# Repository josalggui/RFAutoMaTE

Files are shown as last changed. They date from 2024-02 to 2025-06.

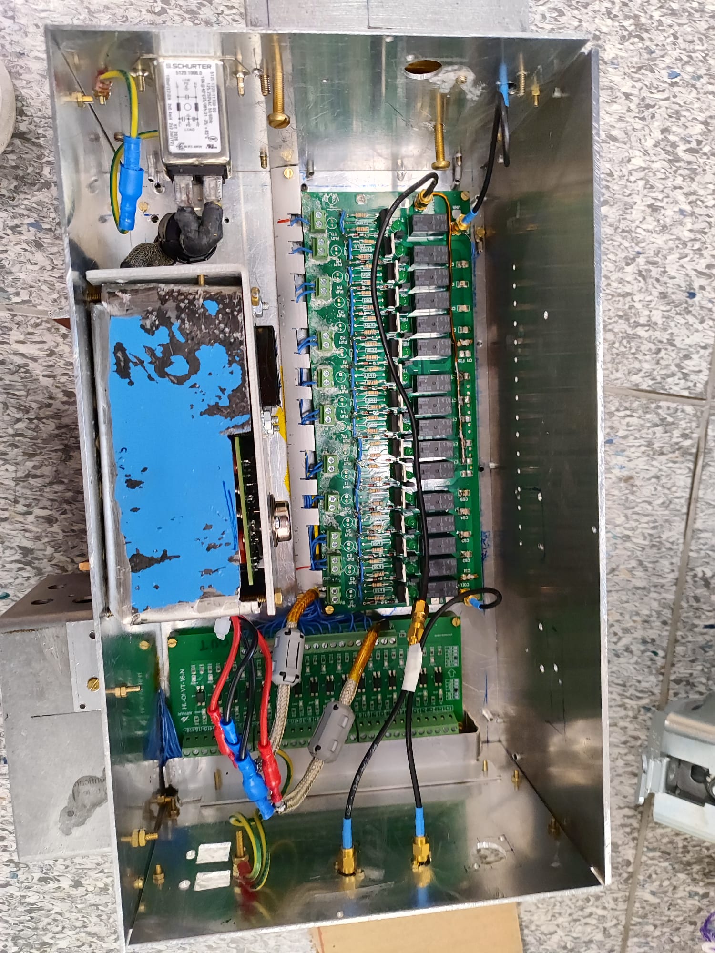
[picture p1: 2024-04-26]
figures/caja 1.jpg

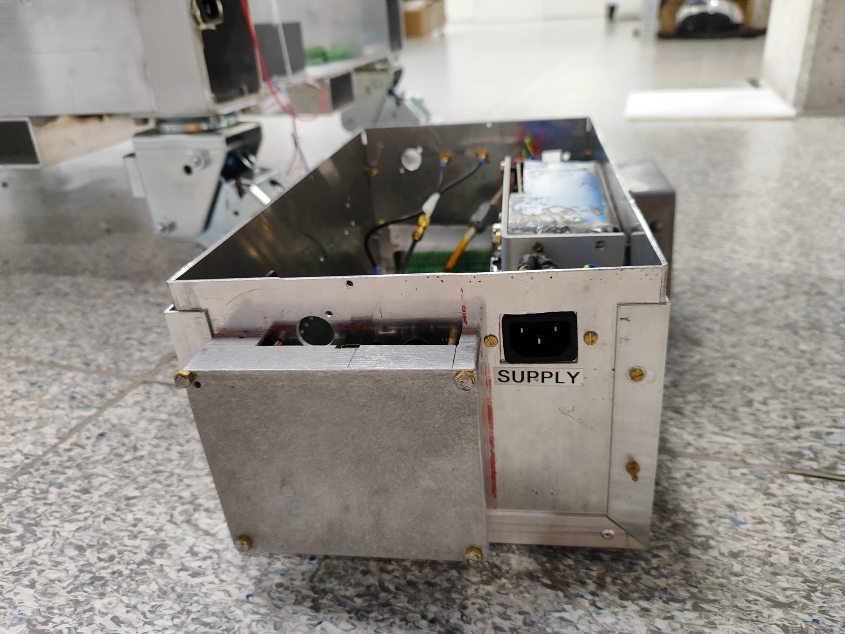
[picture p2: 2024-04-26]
figures/caja 3.jpg

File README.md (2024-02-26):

# RFAutoMaTE - Radio Frequency Automatic Matching and Tuning Equipment

Welcome to RFAutoMaTE, **R**adio **F**requency **Auto**matic **Ma**tching and **T**uning **E**quipment, our go-to solution for seamless Radio Frequency (RF) coil matching and tuning in low-field (< 100 mT) MRI scanners.

## Overview

RFAutoMaTE is designed to provide efficient and automatic matching of RF coils to ensure optimal performance and signal quality in Magnetic Resonance Imaging (MRI) systems.

## Features

- **RF Precision:** Achieve precise Radio Frequency coil matching.
- **AutoMaTE Automation:** Streamlined process with AutoMaTE (Automatic Matching and Tuning) automation.
- **Tuning Efficiency:** Efficient T (Tuning) for enhanced imaging performance.
- **Ease of Use:** E (Equipment) designed for user-friendly operation.

## Getting Started (TODO)

To get started with RFAutoMaTE, follow these simple steps:

1. **Installation:** Clone the repository to your local machine.
   ```bash
   git clone https://github.com/mriLab-i3M/RFAutoMaTE.git

2. **Configura.tion:** Adjust RFAutoMaTE settings according to your system requirements.
3. **Usage:** Integrate RFAuotMaTE into your MRI system for automatic RF coil matching and tuning.

## Testing
To test if relays are working properly, load the `test_arduino.ino` into the arduino and power the RFAutoMaTE. The relays should blink sequencitally.

If everything is ok. load the `autotunig_arduino.ino` into the arduino. Now the user can turn on/off relays by serial communication.

RFAutoMaTE is able to change the impedance by de/activating relays that chanes capacitance to a T circuit. The T circuit includes a series, tuning and matching capacitors.

<img src="figures/Circuit.png">

Each capacitance has up to 5 capacitors, giving a total of 15 pins. An additional
digital signal (TTL) allow the user to switch the tuning matching between the
Tx/Rx switch to run MRI experiments or to the VNA to measure the coil impedance.

User can control the status by sending a set of 16 (15 capacitors + 1 switch) digits to de/activate the
capacitance.
0->Capacitor activated
1->Capacitor deactivated

Last digit correspond the switching between VNA and TxRx switch:
0->TxRx switch
1->VNA

For example, if the user wants to activate all capcitors and connect to TxRx switch:
`0000000000000000`

For the moment, the code does not check the number of digits. So make sure that
the number of digits is 16, otherwise, arduino can get frozen.

## Contributors
1. [Rubén Bosch Esteve](https://github.com/RubenBoschEsteve), circuit design and pcb design
2. [José Miguel Algarín Guisado](https://github.com/josalggui), circuit design, arduino code, integration with [MaRGE](https://github.com/josalggui/MaRGE)

## License
RFAutoMaTE is released under the GNU General Public License (GPL) v3.0.

Feel free to reach out if you have any questions or need assistance.

Happy matching and tuning!

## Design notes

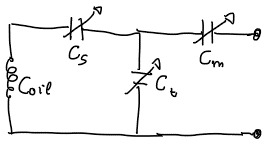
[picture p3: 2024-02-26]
figures/Circuit.png

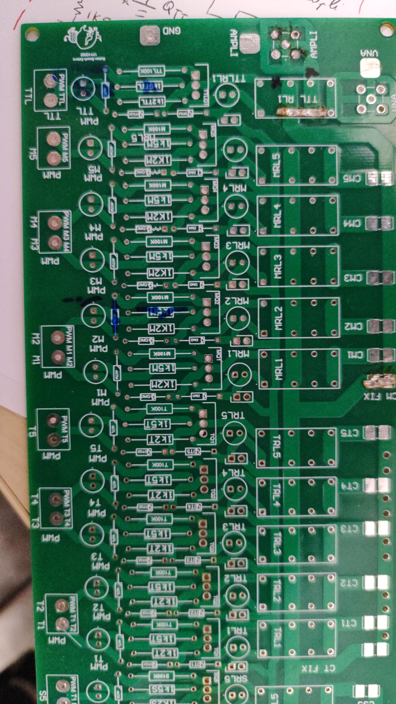
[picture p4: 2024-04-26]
figures/pcb sin montar.jpg

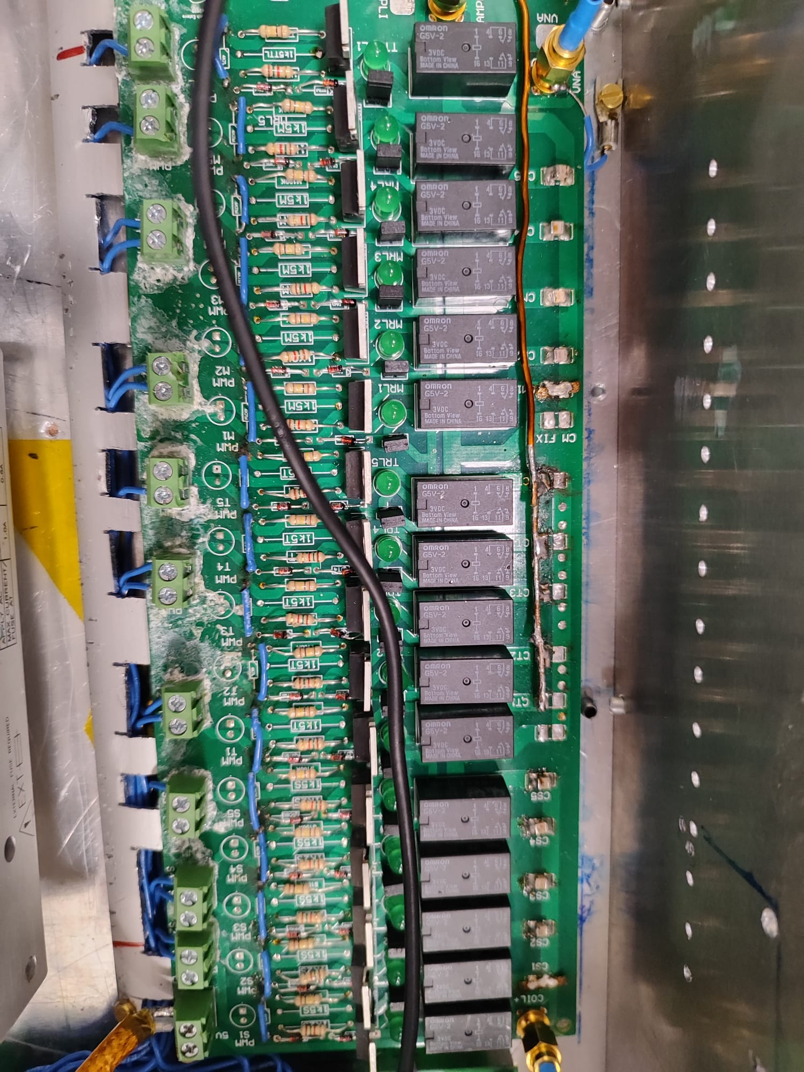
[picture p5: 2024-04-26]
figures/pcb montada 1.jpg

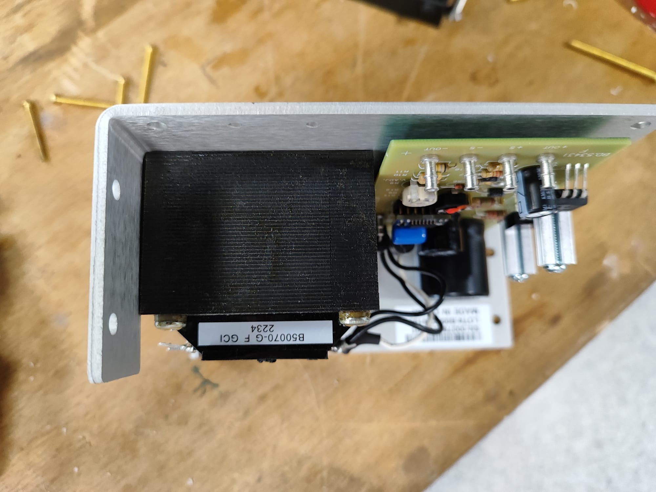
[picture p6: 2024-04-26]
figures/fuente lineal.jpg

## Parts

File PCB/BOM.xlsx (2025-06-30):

Descripción | References | Part number | Link | Quantity | Observaciones
Rele | SRL1…5, TRL1…5, MRL1…5, TTL RL1 | G5V-2-DC3 | MOUSER (https://www.mouser.es/ProductDetail/Omron-Electronics/G5V-2-DC3?qs=sGAEpiMZZMsyYdr3R27aV%252B0%2FGArKNh1e) | 16 | EC - 0039
Mosfet | SQ1…5, TQ1…5, MQ1…5, TTL Q1 | IRFZ44N Mosfet o IRFZ44NPBF | MOUSER (https://www.mouser.es/ProductDetail/Infineon-Technologies/IRFZ44NPBF?qs=9%252BKlkBgLFf24zghzPg2f9g%3D%3D) | 16 | EC - 0038
Jumper Macho | J1-J16 | 251-8086 Jumper macho | RS (https://es.rs-online.com/web/p/conectores-macho-para-pcb/2518086) | 16 | Se ponen en el mismo lugar que los Jumper hembra (EC - 0026)
Diodo | DT1..DT5,DM1…DM5,DS1..DS5,DTQ1..DTQ5,DMQ1…DMQ5,DSQ1..DSQ5,DTTL1,DTTLQ1 | DIODO 1N4148TA | DIGIKEY (https://www.digikey.es/es/products/detail/on-semiconductor/1N4148TA/1532747) | 32 | EC - 0048
Resistencia 1.2k | 1.2k | MRS16000C1201FCT00 | digikey (https://www.digikey.es/es/products/detail/vishay-beyschlag-draloric-bc-components/MRS16000C1201FCT00/5063751) | 16 | EC - 0034
Resistencia 100k | 100k | SFR2500001003JA500 | digikey (https://www.digikey.es/es/products/detail/vishay-beyschlag-draloric-bc-components/SFR2500001003JA500/5065363) | 16 | EC - 0033
Terminal regleta PCB | PMW S1..5, PMW T1..5, PMW M1..5, COIL, GND, 5V | 691213710002 | RS (https://es.rs-online.com/web/p/bornes-para-pcb/8267282?searchId=7f03fc5e-c5a5-46d9-938e-7147ac300166&gb=s) | 11 | EC - 0035
LED | DSRL1..5,DTRL1..5,DMRL1..5,DTTL5 | SLR-56MG3F | DIGIKEY (https://www.digikey.es/es/products/detail/rohm-semiconductor/SLR-56MG3F/636990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) | 16 | EC - 0031
Jumper hembra | J1-J16 | AKSCT/Z BLACK | rs (https://es.rs-online.com/web/p/jumpers-y-derivadores/6742397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) | 16 | EC - 0026
SMA PCB |  | 901-144-8RFX | rs (https://es.rs-online.com/web/p/conectores-coaxiales/1440894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) | 3 | RF - 0007

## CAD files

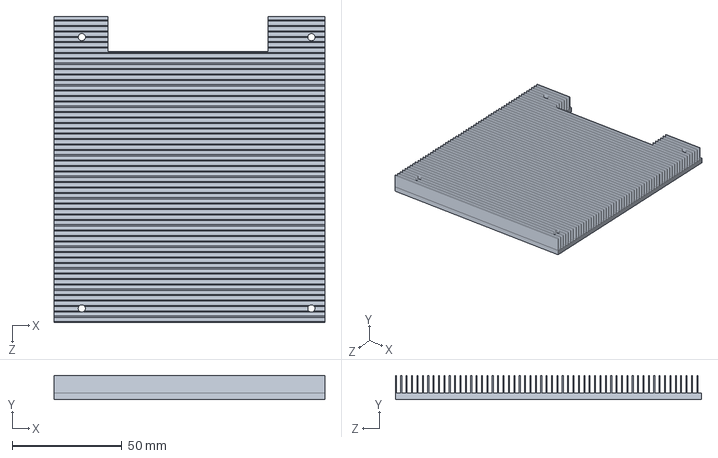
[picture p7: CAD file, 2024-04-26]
Disipador/disipador V2.SLDPRT
123.7 x 11.0 x 139.8 mm

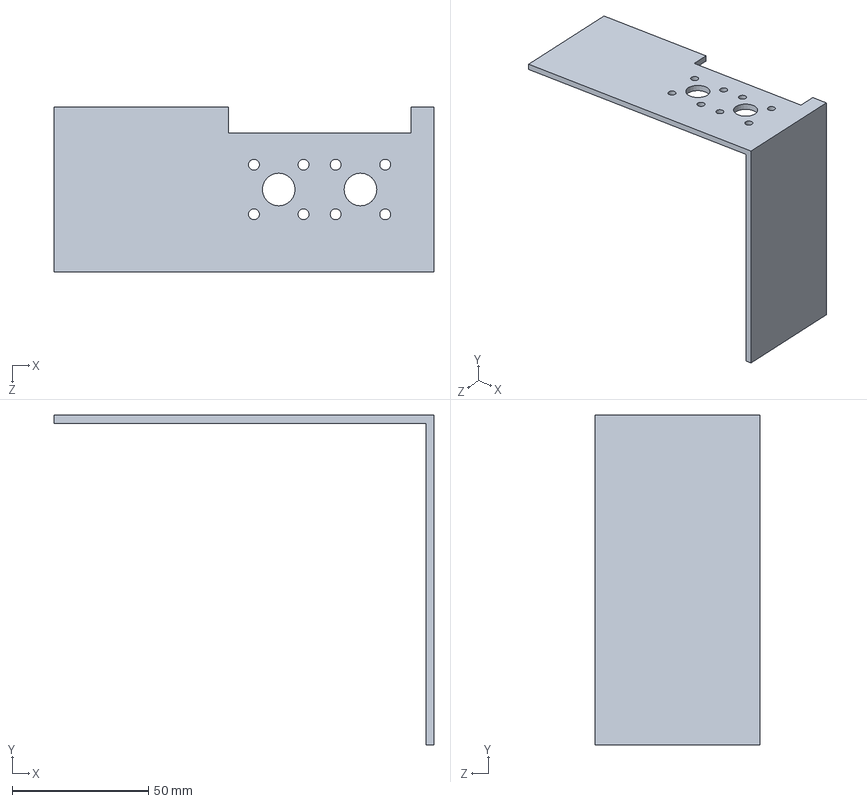
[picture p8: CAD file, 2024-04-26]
Disipador/fuente lineal V2.SLDPRT
139.5 x 121.0 x 60.5 mm

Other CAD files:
Disipador/disipador V2.STL
Disipador/fuente lineal V2.STL

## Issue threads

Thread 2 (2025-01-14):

Implementation of RFAutoMate

LeoMcBills, 2025-01-14:
Hello @josalggui, could you be having more literature on RFAutoMate otherwise I want to implement it for our lab in Uganda but I still do not understand the criteria for choosing the capacitor values.

Also, is there a way I could open the PCB files in KiCad?

Thanks!

josalggui, 2025-02-09:
Hi @LeoMcBills. I apologize for the long delay to answer, but I have important deadlines. Unfortunately I do not have time now to do documentation. I can send you by email what I have from our lab notes if you want. Also, if you want to contribute by doing some documentation based on our notes, it will be great!

LeoMcBills, 2025-02-09:
Hello @Josalggui/Rfautomate,
I hope this email finds you well. It is alright, sending me your notes by
email (this or on  ***@***.***)will be greatly appreciated and I
will update the documentation based on this as I am happy to do so.

Thanks very much for your support always.

Leo

On Sun, Feb 9, 2025, 7:03 PM José Miguel Algarín Guisado <
***@***.***> wrote:

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

--
*DISCLAIMER*

This email and its attachments are, unless the context
clearly indicates otherwise, the property of Mbarara University of Science
and Technology. It is confidential, private and intended for the addressee
only. If you are not an intended recipient you must not use, disclose,
distribute, copy, print or rely on this email. Mbarara University of
Science and Technology accepts no liability to anyone whatsoever for any of
the contents of the email or any of its attachments.

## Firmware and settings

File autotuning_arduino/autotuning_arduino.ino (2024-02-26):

/*
Code to control the RFAutoMaTE with arduino.
Ph.D. José Miguel Algarín Guisado
mriLab, i3M, CSIC, Valencia, Spain
RFAutoMaTE is able to change the impedance by de/activating relays that adds c
apacitance to a T circuit. The T circuit include a series capacitor, tuning and
matching.

|---------||-------------||-------*
|         Cs     |       Cm
c                |
c Coil          | | Ct
c                |
|                |
|---------------------------------*

Each capacitance has up to 5 capacitors, giving a total of 15 pins. An additional
digital signal (TTL) allow the user to switch the tuning matching between the
Tx/Rx switch to run MRI experiments or to the VNA to measure the coil impedance.

User can control the status by sending a set of 16 digits to de/activate the
capacitance.
0->Capacitor activated
1->Capacitor deactivated

Last digit correspond the switching between VNA and TxRx switch:
0->TxRx switch
1->VNA

For example, if the user wants to activate all capcitors and connect to TxRx switch:
0000000000000000

For the momento, the code does not check the number of digits. So make sure that
the number of digits is 16, otherwise, arduino can look frozen.

*/

// Code to control the autotuning circuit with python.
//  cPins[] = {S1, S2, S3, S4, S5, T1, T2, T3, T4, T5, M1, M2, M3, M4, M5, TTL}
int cPins[] = {23, 31, 29, 27, 25, 41, 39, 37, 35, 33, 43, 51, 49, 47, 45, 53};
int nPins = 16;

void setup() {
  // Start the Serial communication
  Serial.begin(115200);
  Serial.setTimeout(100);
  // Set the pins for tuning, matching and series capacitors
  for (int c=0; c<nPins; c++) {
    pinMode(cPins[c], OUTPUT);
  }
}

void loop() {
  // Wait until there are any data available into the serial port
  if (Serial.available()>0) {
    delay(10);
    String state = Serial.readString();
    for (int c=0; c<nPins; c++) {
      digitalWrite(cPins[c], String(state[c]).toInt());
    }
    Serial.write("Ready!\n");
  }

}

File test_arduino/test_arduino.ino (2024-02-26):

/*
Code to test RFAutoMaTE.
Ph.D. José Miguel Algarín Guisado
mriLab, i3M, CSIC, Valencia, Spain

This code should blink all the relays secuentially. The user should see leds

*/

// Number of digital outputs
const int numOutputs = 16;

// Define the digital output pins
int outputPins[numOutputs] = {23, 31, 29, 27, 25, 41, 39, 37, 35, 33, 43, 51, 49, 47, 45, 53};

// Time delay for blinking in milliseconds
const int blinkDelay = 500;

void setup() {
  // Set all digital output pins as OUTPUT
  for (int i = 0; i < numOutputs; i++) {
    pinMode(outputPins[i], OUTPUT);
  }
}

void loop() {
  // Blink each output one by one
  for (int i = 0; i < numOutputs; i++) {
    digitalWrite(outputPins[i], HIGH);  // Turn on
    delay(blinkDelay);
    digitalWrite(outputPins[i], LOW);   // Turn off
    delay(blinkDelay);
  }
}

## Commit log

2024-01-24 [JMA] First Commit
    [BOM autotuning.xlsx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]
2024-02-26 I upladed the codes for arduino.
2024-02-26 Added hand made circuit
2024-04-26 Update of the repo to the first tested version. V1.0.0
    [BOM autotuning.xlsx, BOM.xlsx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]
2024-04-26 We added a heat sink to avoid overtermperature of the linear power supply. Tested. V1.1
    [disipador V2.SLDPRT, disipador V2.STL, fuente lineal V2.SLDPRT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]
2025-06-30 Add files via upload
    Update of RFAutoMATE BOM.xlsx
2025-06-30 BOM modification for optocoupler compatibility
    [BOM.xlsx]
